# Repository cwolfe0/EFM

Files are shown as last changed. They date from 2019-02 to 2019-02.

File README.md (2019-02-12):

# Electric Field Meter
This is a PCB designed in KiCad for the UAH SHC HELEN project's Electric Field Meter.  This PCB is intended to receive a current on the two-input molex connector that will vary as two metal spheres spin around several axes in a thunderstorm.  The current is converted to a readable voltage and then shifted up utilizing a weighted summer and the -2.8V line used to power the opamps.  It is shifted such that it approximately maximizes the range that the MCU's ADC can read while powered with 2.8V, from ~0-1.2V.

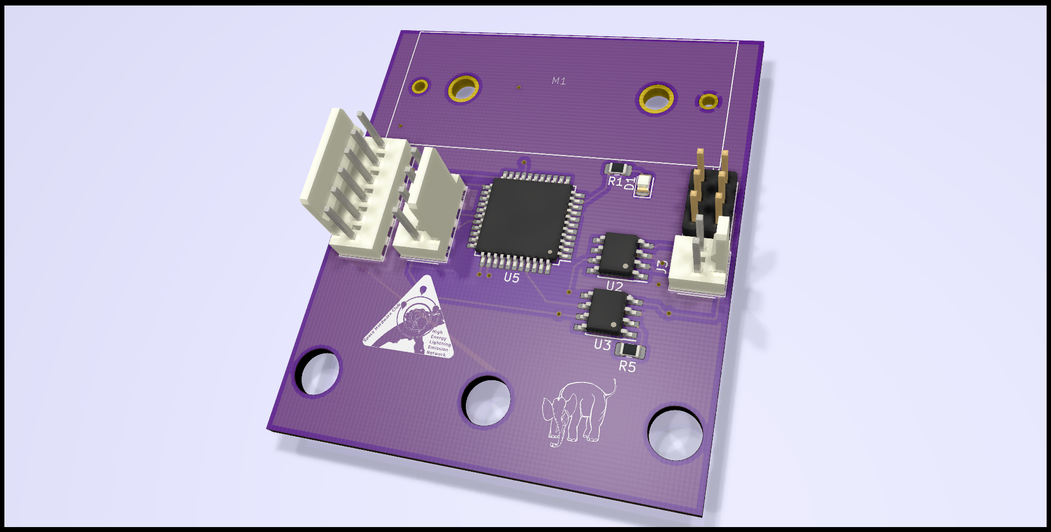
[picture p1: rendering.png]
PCB Rendering in KiCad


The rendering above is a rough idea of what this payload will look like with some of its components installed.

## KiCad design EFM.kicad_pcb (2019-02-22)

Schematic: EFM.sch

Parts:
C1, C2, C3, C6: 1u; C_0805_2012Metric_Pad1.15x1.40mm_HandSolder
C4: 4.7u; C_0805_2012Metric_Pad1.15x1.40mm_HandSolder
C5, C7, C9: 10u; C_0805_2012Metric_Pad1.15x1.40mm_HandSolder
C8, C10: 0.1u; C_0805_2012Metric_Pad1.15x1.40mm_HandSolder
D1: LED; LED_0805_2012Metric
FB1: FB; L_0805_2012Metric_Pad1.15x1.40mm_HandSolder
J1: Openlog; Molex_KK-254_AE-6410-06A_1x06_P2.54mm_Vertical
J2: IMU; Molex_KK-254_AE-6410-04A_1x04_P2.54mm_Vertical
J3: Spheres; Molex_KK-254_AE-6410-02A_1x02_P2.54mm_Vertical
J4: AVR-PDI-6; PinHeader_2x03_P2.54mm_Vertical
L1: L_Small; L_0805_2012Metric_Pad1.15x1.40mm_HandSolder
M1: SHC_123_BATTERY_HOLDERCR-123-A; SHC_CR-123-A_HOLDER
R1: 220; R_0805_2012Metric_Pad1.15x1.40mm_HandSolder
R2: 1M; R_0805_2012Metric_Pad1.15x1.40mm_HandSolder
R3: 1k; R_0805_2012Metric_Pad1.15x1.40mm_HandSolder
R4: 28k; R_0805_2012Metric_Pad1.15x1.40mm_HandSolder
R5: 6k; R_0805_2012Metric_Pad1.15x1.40mm_HandSolder
R6: 10k; R_0805_2012Metric_Pad1.15x1.40mm_HandSolder
U1: TPS60400DBVR
U2, U3: LM741; SOIC-8_3.9x4.9mm_P1.27mm
U4: XCL206B; 6-TDFN
U5: ATxmega32A4U-AU; TQFP-44_10x10mm_P0.8mm

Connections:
/+2.8V: C2.1, C5.2, J2.3, J4.2 (VCC), L1.1, R6.1, U1.2, U2.7 (V+), U3.7 (V+), U4.3 (Vout), U4.8 (L2)
/-2.8V: C1.2, R4.2, U1.1, U2.4 (V-), U3.4 (V-)
/BATT: C4.1, J1.4, M1.+, U4.4 (CE), U4.6 (Vin)
/LED: R1.2, U5.10 (PC0)
/PDI-CLK: J4.5 (CLOCK), R6.2, U5.35 (~RESET~/PDI_CLK)
/PDI-DATA: J4.1 (DATA), U5.34 (PDI_DATA)
/RXD: J1.3, U5.22 (PD2)
/S1: C3.2, J3.2, R2.2, U2.2 (-)
/SCLE: J2.1, U5.29 (PE1)
/SDAD: J2.2, U5.28 (PE0)
/TXD: J1.2, U5.23 (PD3)
/VOUT: R5.1, U3.6, U5.41 (PA1)
GND: C1.1, C2.2, C4.2, C5.1, C7.2, C8.2, C9.1, C10.1, D1.1 (K), J1.5, J2.4, J3.1, J4.6 (GND), M1.-, U1.4, U2.3 (+), U3.3 (+), U4.2 (Vss), U4.5 (Vss), U5.8 (GND), U5.18 (GND), U5.30 (GND), U5.38 (GND)
unnamed: C3.1, R2.1, R3.2, U2.6
unnamed: C6.1, U1.5
unnamed: C6.2, U1.3
unnamed: C7.1, C8.1, FB1.2, L1.2, U5.9 (VCC), U5.19 (VCC), U5.31 (VCC)
unnamed: C9.2, C10.2, FB1.1, U5.39 (AVCC)
unnamed: D1.2 (A), R1.1
unnamed: R3.1, R4.1, R5.2, U3.2 (-)
unnamed: U4.1 (Lx), U4.7 (L1)

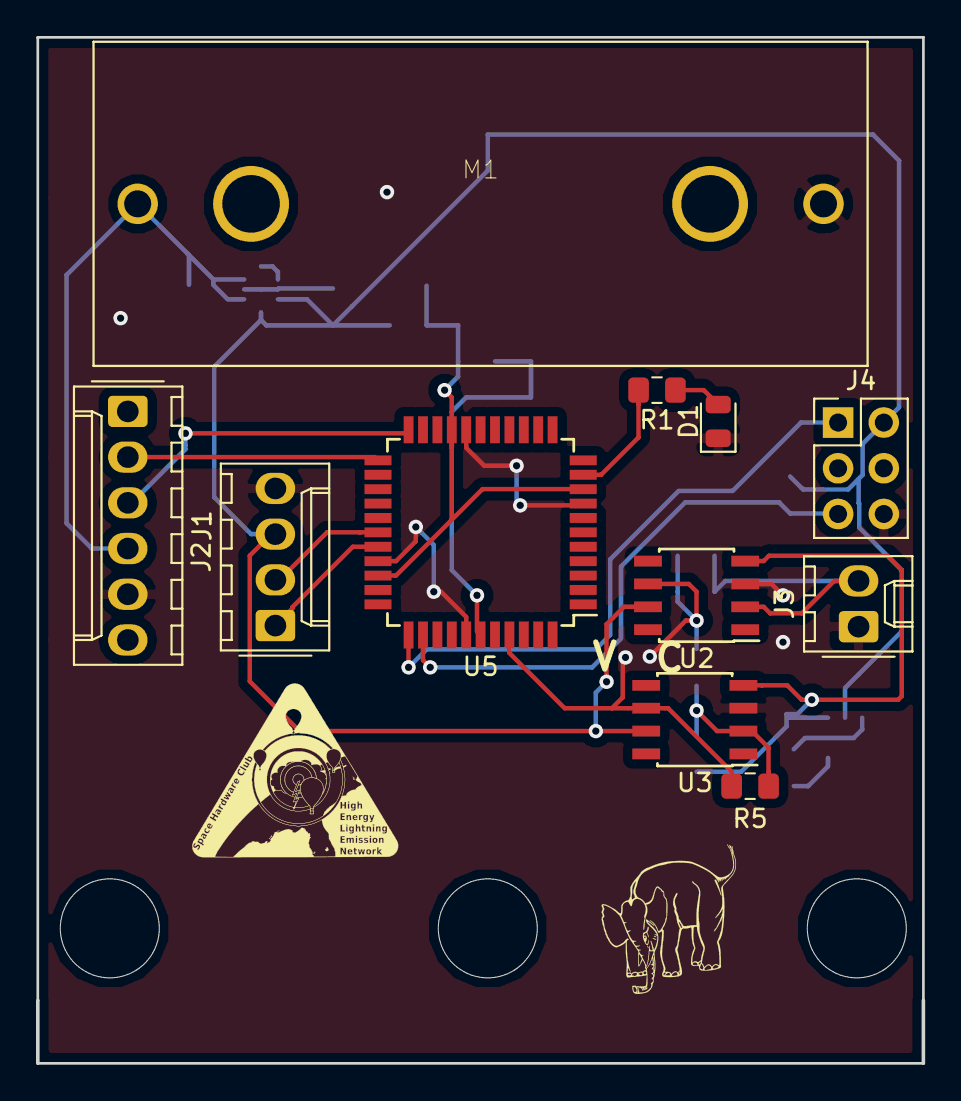
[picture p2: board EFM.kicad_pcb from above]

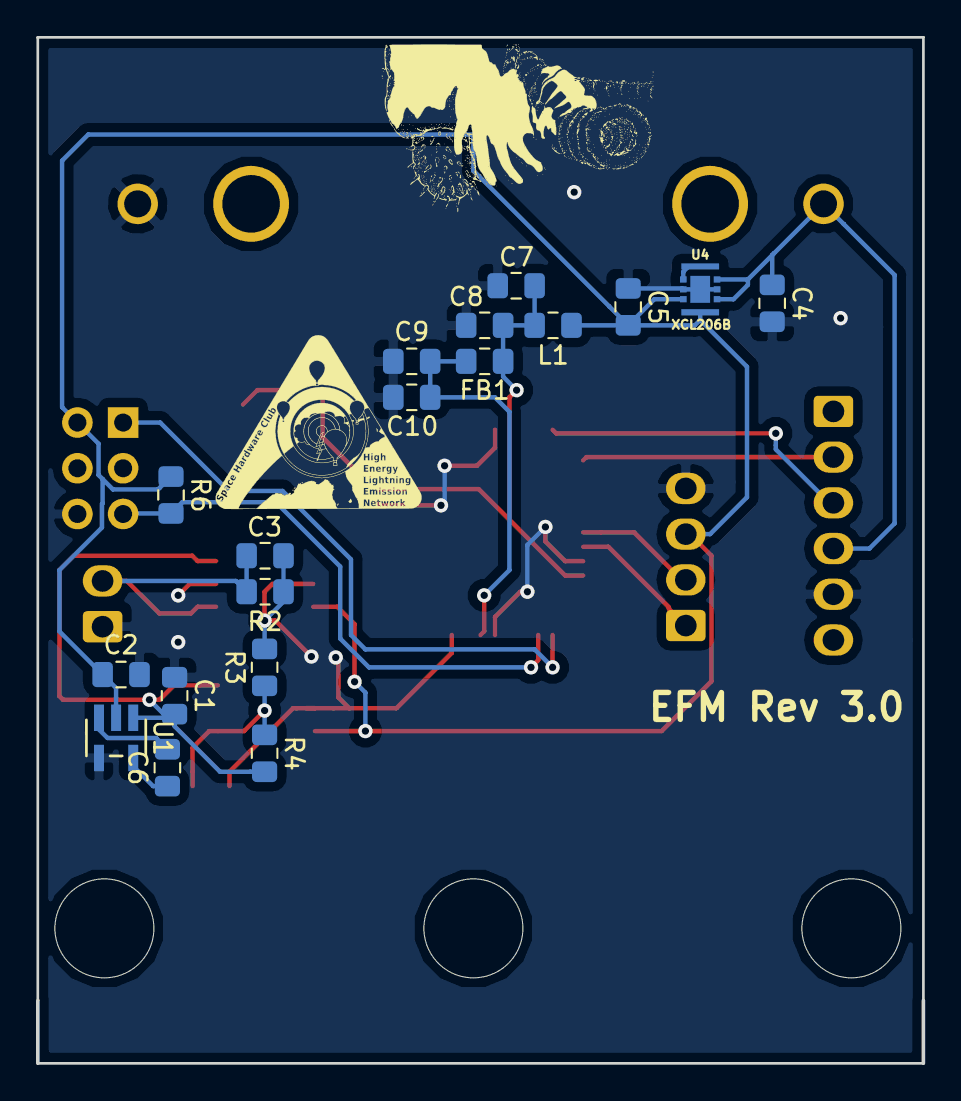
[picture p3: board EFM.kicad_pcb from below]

Board: 2 copper layers, 49.2 x 57.0 mm, 29 parts (18 on the bottom side), 21 nets.

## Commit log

2018-02-18 fixing stuff
    [EMF.brd, EMF.sch]
2018-02-20 fix op-amp connections
    [EMF.brd, EMF.sch]
2018-02-20 fix naming convention
    [EMF.brd, EMF.sch]
2018-02-26 Added HELEN logo and musical imagery as tax
    [EMF.brd]
2018-02-26 add gerber zip for OSHPark
2018-02-26 Changing logo stuff, added gerber zip
    [EMF.brd]
2018-10-17 Make fixes, remove XBEE, add screw holes
    [EMF.brd]
2018-10-17 not 100% sure what changed, hopefully not much
    [EMF.brd]
2018-10-18 Remake Gerbers for updated design
2018-10-18 Fix component being under other component, remake Gerbers
2018-10-19 Add dimensions for drills
2019-02-02 delet this too
    [EMF.brd]
2019-02-02 Update gerbers, board frigged up so the eagle board isn't accurate/not functional
2019-02-12 Move to KiCAD, add 2.8V regulator and make op-amp output to MCU >0V
    [EFM-B.Cu.gbr, EFM-B.Mask.gbr, EFM-B.Paste.gbr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]
2019-02-12 Add silkscreen logos/info and add render
    [EFM-B.Cu.gbr, EFM-B.Mask.gbr, EFM-B.Paste.gbr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]
2019-02-22 Small updates
    [EFM.kicad_pcb]
2019-02-22 Add dimensions for mounting holes
    [EFM.kicad_pcb]

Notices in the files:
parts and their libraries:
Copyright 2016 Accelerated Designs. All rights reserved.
